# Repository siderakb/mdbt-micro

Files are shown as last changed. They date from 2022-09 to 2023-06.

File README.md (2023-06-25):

# MDBTMicro

v1.3

*MDBTMicro-50Q* is an alternative board to [nRFMicro](https://github.com/joric/nrfmicro)/Pro Micro.

It has USB Type-C and LiPo charger, uses Raytac [MDBT50Q-*x*1MV2](https://www.raytac.com/product/ins.php?index_id=24) nRF52840 module (or [MDBT50Q-*x*512K](https://www.raytac.com/product/ins.php?index_id=95) nRF52833 module) instead of E73-2G4M08S1.

Go to [Releases](https://github.com/siderakb/mdbt-micro/releases) for schematic and Gerber files.

> A part of [ErgoSNM keyboard](https://github.com/siderakb/ergo-snm-keyboard) project.  
> EDA: KiCad  

## PCB
| Front | Back | Layers |
| --- | --- | --- |
|  |  |  |

## BOM
| Designator | Value | Footprint |
| --- | --- | --- |
| C1,C2 | 1uF | 0603 (1608 Metric) |
| C3,C4 | 12pF | 0603 (1608 Metric) |
| R1 | 100k | 0603 (1608 Metric) |
| R2,R4 | 1k | 0603 (1608 Metric) |
| R3 | *Rprog* | 0603 (1608 Metric) |
| R5 | 1k | **0402 (1005 Metric)** |
| R6 | 820k | 0603 (1608 Metric) |
| R7,R8 | 2M | 0603 (1608 Metric) |
| R9,R10 | 5.1k | 0603 (1608 Metric) |
| D1 | 1N5819 | SOD-323F |
| J2 | USB_C_Receptacle_USB2.0 | 918-418K2024S40000 |
| LD1 | Red | 0603 (1608 Metric) |
| LD2 | Blue | 0603 (1608 Metric) |
| LD3 | Green | **0402 (1005 Metric)** |
| Q1,Q2 | AO3407 | Package_TO_SOT_SMD:SOT-23 |
| U1 | XC6220B331MR-G | SOT-23-5 |
| U2 | MDBT50Q-x1MV2 | MDBT50Q |
| U3 | TP4057 | SOT-23-6 |
| X1 | 32.768kHz | 2Pin 3.2x1.5mm |

- Please note that the footprint of R5 and LD3 is 0402.
- R2, R3, U3 and LD1 are not necessary if LiPo charger is not required. 
- R6 and R7 are not necessary if LiPo battery monitor is not required.
- Adjust the LiPo charging current with the value of R3.
  - 20 kΩ: 50 mA
  - 10 kΩ: 100 mA
  - 5 kΩ: 200 mA
  - 4 kΩ: 250 mA
  - 3 kΩ: 300 mA
  - 2 kΩ: 400 mA
  - 1.6 kΩ: 500 mA 
- XC6220B331MR-G can be replaced by AP2112K-3.3.
- MDBT50Q module includes MDBT50Q-1MV2/P1MV2/U1MV2 (nRF52840-based), or MDBT50Q-512K/P512K/U512K (nRF52833-based).

There is not designator silkscreen on PCB, please use your browser to open the `ibom.html` file (placed in [release page][release]) to refer to the placement of the parts, it is generated by [Interactive HTML BOM](https://github.com/openscopeproject/InteractiveHtmlBom) plugin.

## Pinout
| MDBTMicro-50Q `1.4` | nRFMicro `1.4` | Pro Micro | <--> | Pro Micro | nRFMicro `1.4` | MDBTMicro-50Q `1.4` |
| :---: | :---: | :---: | :---: | :---: | :---: | :---: |
| GND | GND | -- | | -- | VBAT | VBAT |
| P0.06 | P0.06 | D1/Tx | | RAW | VBAT | VBUS (USB 5V) |
| P0.08 | P0.08 | D0/Rx | | GND | GND | GND |
| GND | GND | GND | | RST |  P0.18/RESET | P0.18/RESET |
| GND | GND | GND | | VCC | VDD & VDDH | VDD & VDDH |
| P0.15 | P0.15 | D2 | | A3 | P0.30 | P0.30 |
| P0.17 | P0.17 | D3 | | A2 | P0.31 | P0.31 |
| P0.20 | P0.20 | D4 | | A1 | P0.29 | P0.29 |
| P0.13 | P0.13 | D5 | | A0 | P0.02 | P0.02 |
| P0.24 | P0.24 | D6 | | D15 | P1.13 | P1.13 (*P1.05*) |
| P0.09 | P0.09 | D7 | | D14 | P0.03 | P0.03 |
| P0.10 | P0.10 | D8 | | D16 | P0.28 | P0.28 |
| P1.06 | P1.06 | D9 | | D10 | P1.11 | P1.11 (*P1.04*) |
| | | | | | | |
| P1.10 (*P0.25*) | P1.10 | -- | LED Pin | | | |
| P0.04 | P0.04 | -- | Battery Pin | | | |
| P1.09 | P1.09 | -- |  Power Pin  | | | |
| P1.12 (*P0.23*) | -- | -- | TP1 | | | |
| P1.14 (*P1.03*) | -- | -- | TP2 | | | |
| P1.15 (*P0.19*) | -- | -- | TP3 | | | |
| P0.05 | -- | -- | TP4 | | | |
| P0.07 | -- | -- | TP5 | | | |
| P0.11 | -- | -- | TP6 | | | |
| P0.12 | -- | -- | TP7 | | | |

> Italics in brackets for MDBT50Q-*x*512K (nRF52833) pins, otherwise MDBT50Q-*x*1MV2 (nRF52840).  
> Almost the same as [nRFMicro 1.4](https://github.com/joric/nrfmicro/releases/tag/1.4)

## Jumper Config
- JP1
  - nRF52840: Open
  - nRF52833: Close

## Board Characteristics
- Copper layer count: 2
- Board overall dimensions: 33.02 mm x 17.78 mm (1.3 x 0.7 inch)
- Min track/spacing: 0.127 mm / 0.127 mm
- Min hole diameter: 0.3 mm

## Disclaimer
These files without warranty of any kind, use at your own risk, it is recommended to check yourself before manufacture.

For the full statement, please see [LICENSE](./LICENSE).

[release]: https://github.com/ziteh/mdbt-micro/releases

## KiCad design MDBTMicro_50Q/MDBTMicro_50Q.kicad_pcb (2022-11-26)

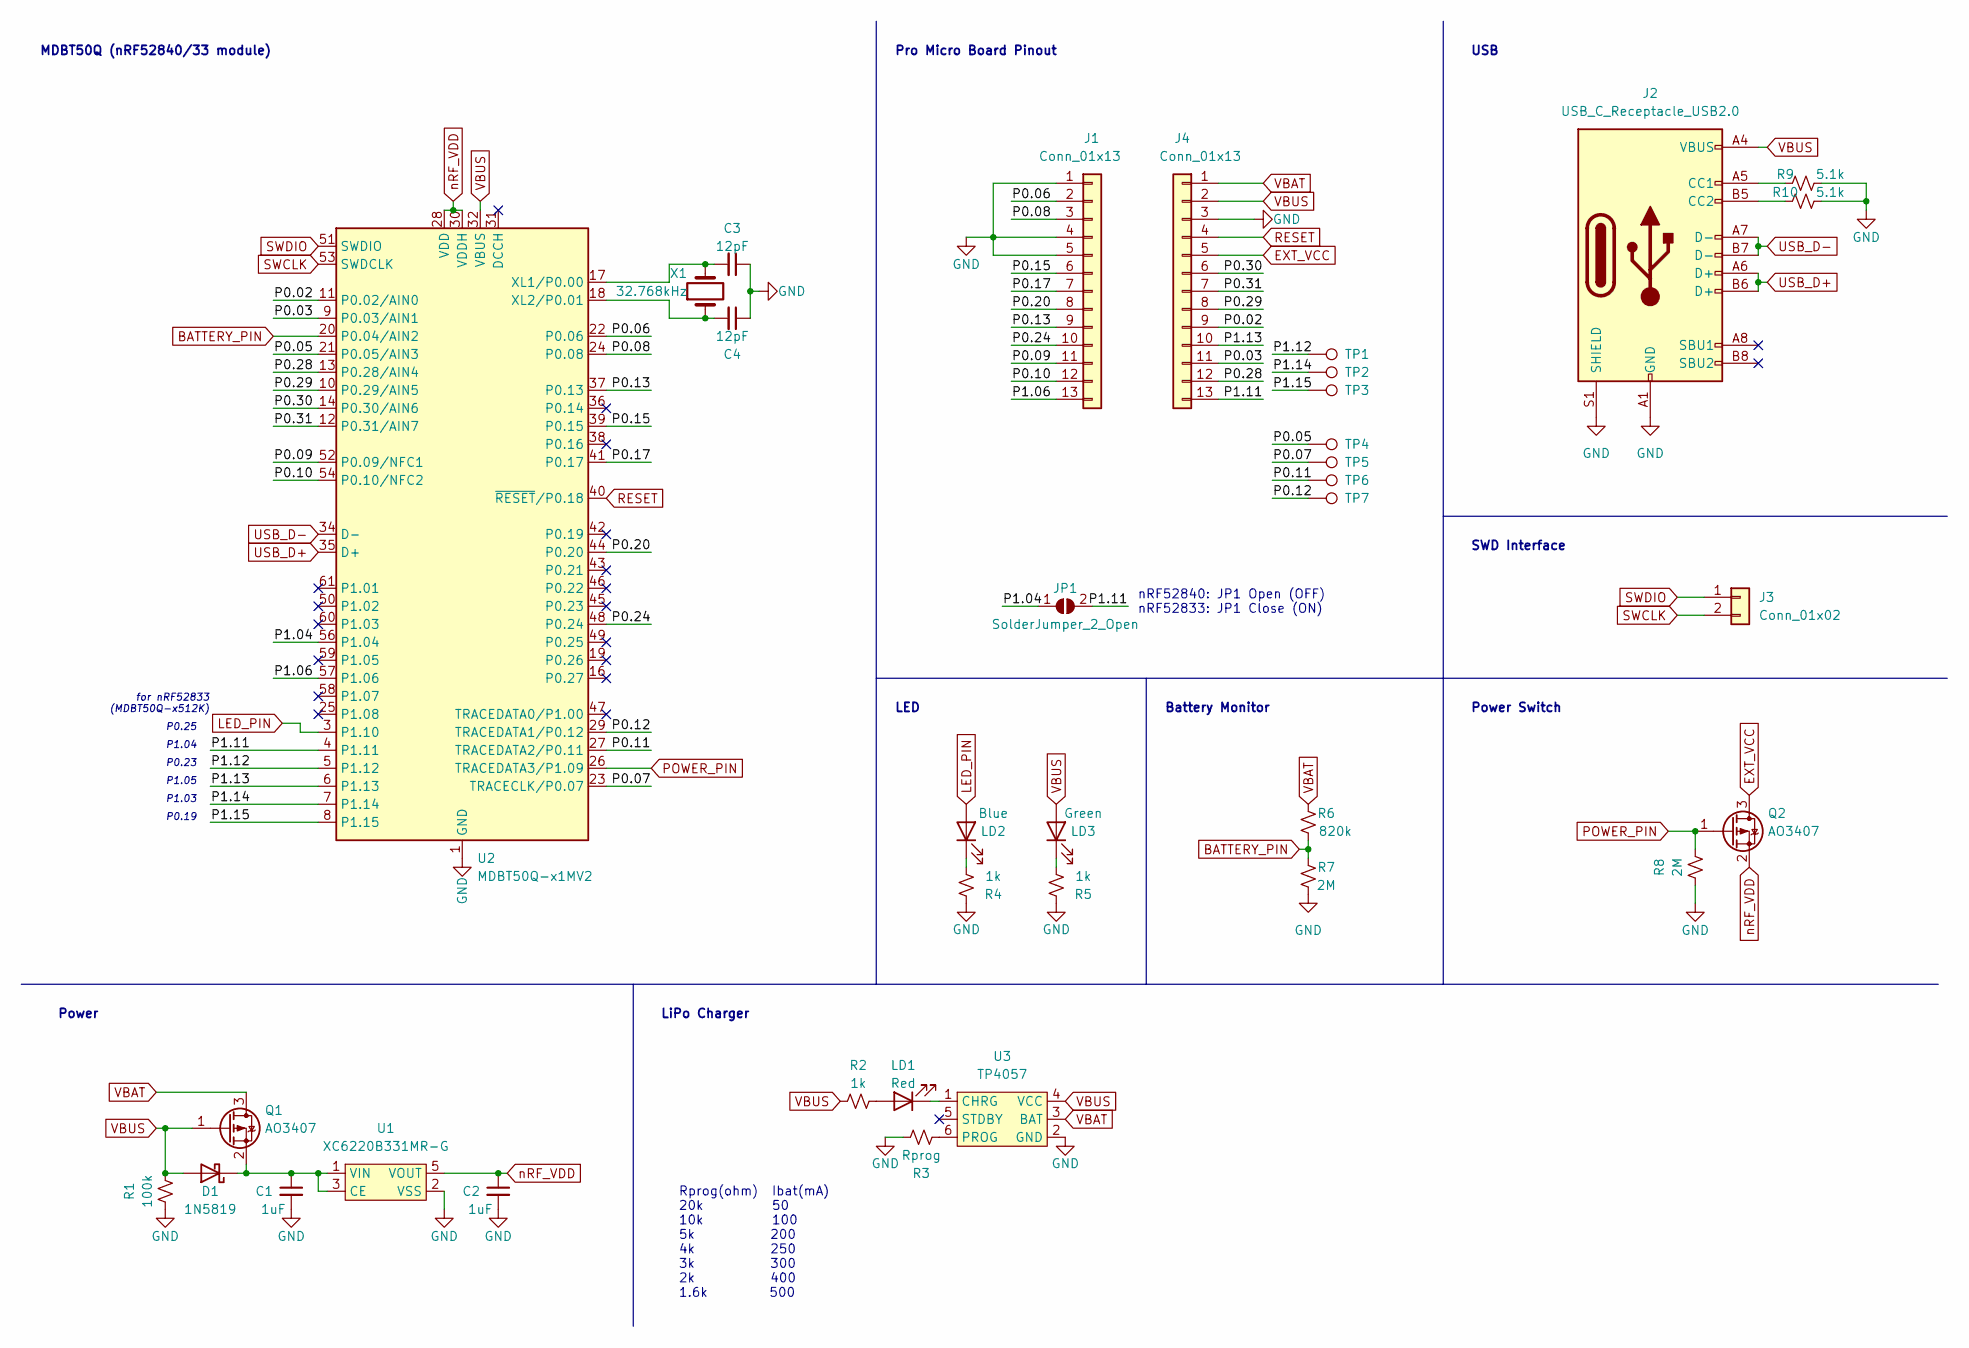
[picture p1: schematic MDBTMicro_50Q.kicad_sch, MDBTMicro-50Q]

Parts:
C1, C2: 1uF; C_0603_1608Metric
C3, C4: 12pF; C_0603_1608Metric
D1: 1N5819; D_SOD-323F
J1, J4: Conn_01x13; PinHeader_1x13_P2.54mm_Vertical
J2: USB_C_Receptacle_USB2.0; USB Type-C Mid-Mount Receptacle 16P
J3: Conn_01x02; PinHeader_1x02_P2.54mm_Vertical
JP1: SolderJumper_2_Open; SolderJumper-2_P1.3mm_Open_TrianglePad1.0x1.5mm
LD1: Red; LED_0603_1608Metric
LD2: Blue; LED_0603_1608Metric
LD3: Green; LED_0402_1005Metric
Q1, Q2: AO3407; SOT-23
R1: 100k; R_0603_1608Metric
R2, R4: 1k; R_0603_1608Metric
R3: Rprog; R_0603_1608Metric
R5: 1k; R_0402_1005Metric
R6: 820k; R_0603_1608Metric
R7, R8: 2M; R_0603_1608Metric
R9, R10: 5.1k; R_0603_1608Metric
TP1, TP2, TP3, TP4, TP5, TP6, TP7: TestPoint; TestPoint_Pad_D1.0mm
U1: XC6220B331MR-G; SOT-23-5
U2: MDBT50Q-x1MV2; Raytac_MDBT50Q
U3: TP4057; SOT-23-6
X1: 32.768kHz; Crystal_SMD_MicroCrystal_CC7V-T1A-2Pin_3.2x1.5mm

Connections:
/P0.02: J4.9, U2.11 (P0.02/AIN0)
/P0.03: J4.11, U2.9 (P0.03/AIN1)
/P0.05: TP4.1, U2.21 (P0.05/AIN3)
/P0.06: J1.2, U2.22 (P0.06)
/P0.07: TP5.1, U2.23 (TRACECLK/P0.07)
/P0.08: J1.3, U2.24 (P0.08)
/P0.09: J1.11, U2.52 (P0.09/NFC1)
/P0.10: J1.12, U2.54 (P0.10/NFC2)
/P0.11: TP6.1, U2.27 (TRACEDATA2/P0.11)
/P0.12: TP7.1, U2.29 (TRACEDATA1/P0.12)
/P0.13: J1.9, U2.37 (P0.13)
/P0.15: J1.6, U2.39 (P0.15)
/P0.17: J1.7, U2.41 (P0.17)
/P0.20: J1.8, U2.44 (P0.20)
/P0.24: J1.10, U2.48 (P0.24)
/P0.28: J4.12, U2.13 (P0.28/AIN4)
/P0.29: J4.8, U2.10 (P0.29/AIN5)
/P0.30: J4.6, U2.14 (P0.30/AIN6)
/P0.31: J4.7, U2.12 (P0.31/AIN7)
/P1.04: JP1.1 (A), U2.56 (P1.04)
/P1.06: J1.13, U2.57 (P1.06)
/P1.11: J4.13, JP1.2 (B), U2.4 (P1.11)
/P1.12: TP1.1, U2.5 (P1.12)
/P1.13: J4.10, U2.6 (P1.13)
/P1.14: TP2.1, U2.7 (P1.14)
/P1.15: TP3.1, U2.8 (P1.15)
BATTERY_PIN: R6.1, R7.2, U2.20 (P0.04/AIN2)
EXT_VCC: J4.5, Q2.3 (D)
GND: C1.2, C2.2, C3.1, C4.1, J1.1, J1.4, J1.5, J2.A1 (GND), J2.A12 (GND), J2.B1 (GND), J2.B12 (GND), J2.S1 (SHIELD), J4.3, R1.2, R3.1, R4.1, R5.1, R7.1, R8.2, R9.2, R10.2, U1.2 (VSS), U2.1 (GND), U2.2 (GND), U2.15 (GND), U2.33 (GND), U2.55 (GND), U3.2 (GND)
LED_PIN: LD2.2 (A), U2.3 (P1.10)
unnamed: C1.1, D1.1 (K), Q1.2 (S), U1.1 (VIN), U1.3 (CE)
unnamed: C3.2, U2.17 (XL1/P0.00), X1.2
unnamed: C4.2, U2.18 (XL2/P0.01), X1.1
unnamed: J2.A5 (CC1), R9.1
unnamed: J2.B5 (CC2), R10.1
unnamed: LD1.1 (K), U3.1 (CHRG)
unnamed: LD1.2 (A), R2.1
unnamed: LD2.1 (K), R4.2
unnamed: LD3.1 (K), R5.2
unnamed: R3.2, U3.6 (PROG)
POWER_PIN: Q2.1 (G), R8.1, U2.26 (TRACEDATA3/P1.09)
RESET: J4.4, U2.40 (~RESET/P0.18)
SWCLK: J3.2, U2.53 (SWDCLK)
SWDIO: J3.1, U2.51 (SWDIO)
USB_D+: J2.A6 (D+), J2.B6 (D+), U2.35 (D+)
USB_D-: J2.A7 (D-), J2.B7 (D-), U2.34 (D-)
VBAT: J4.1, Q1.3 (D), R6.2, U3.3 (BAT)
VBUS: D1.2 (A), J2.A4 (VBUS), J2.A9 (VBUS), J2.B4 (VBUS), J2.B9 (VBUS), J4.2, LD3.2 (A), Q1.1 (G), R1.1, R2.2, U2.32 (VBUS), U3.4 (VCC)
nRF_VDD: C2.1, Q2.2 (S), U1.5 (VOUT), U2.28 (VDD), U2.30 (VDDH)

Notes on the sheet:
Pro Micro Board Pinout
P0.19
LiPo Charger
P0.23
Power Switch
SWD Interface
P1.05
Battery Monitor
Power
Rprog(ohm) Ibat(mA) 20k 50 10k 100 5k 200 4k 250 3k 300 2k 400 1.6k 500
P1.03
P1.04
for nRF52833 (MDBT50Q-x512K)
MDBT50Q (nRF52840/33 module)
USB
P0.25
LED
nRF52840: JP1 Open (OFF) nRF52833: JP1 Close (ON)

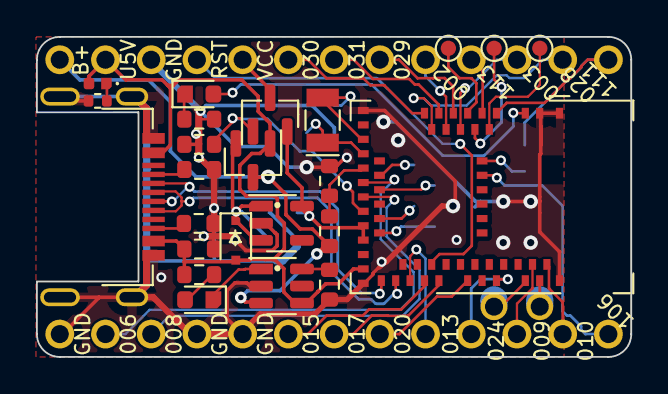
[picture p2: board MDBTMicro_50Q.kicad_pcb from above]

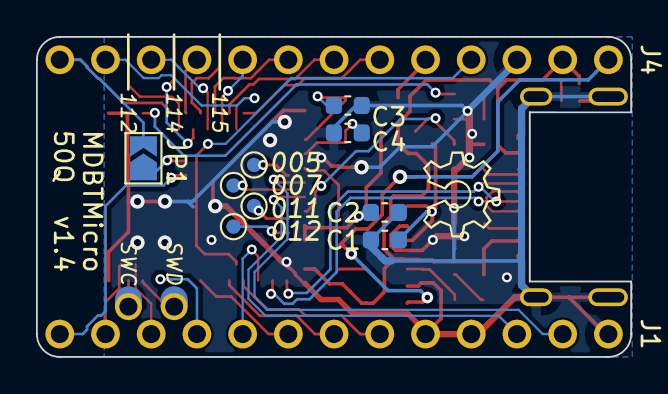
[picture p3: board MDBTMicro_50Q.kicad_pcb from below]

Board: 2 copper layers, 33.0 x 17.8 mm, 36 parts (11 on the bottom side), 49 nets.

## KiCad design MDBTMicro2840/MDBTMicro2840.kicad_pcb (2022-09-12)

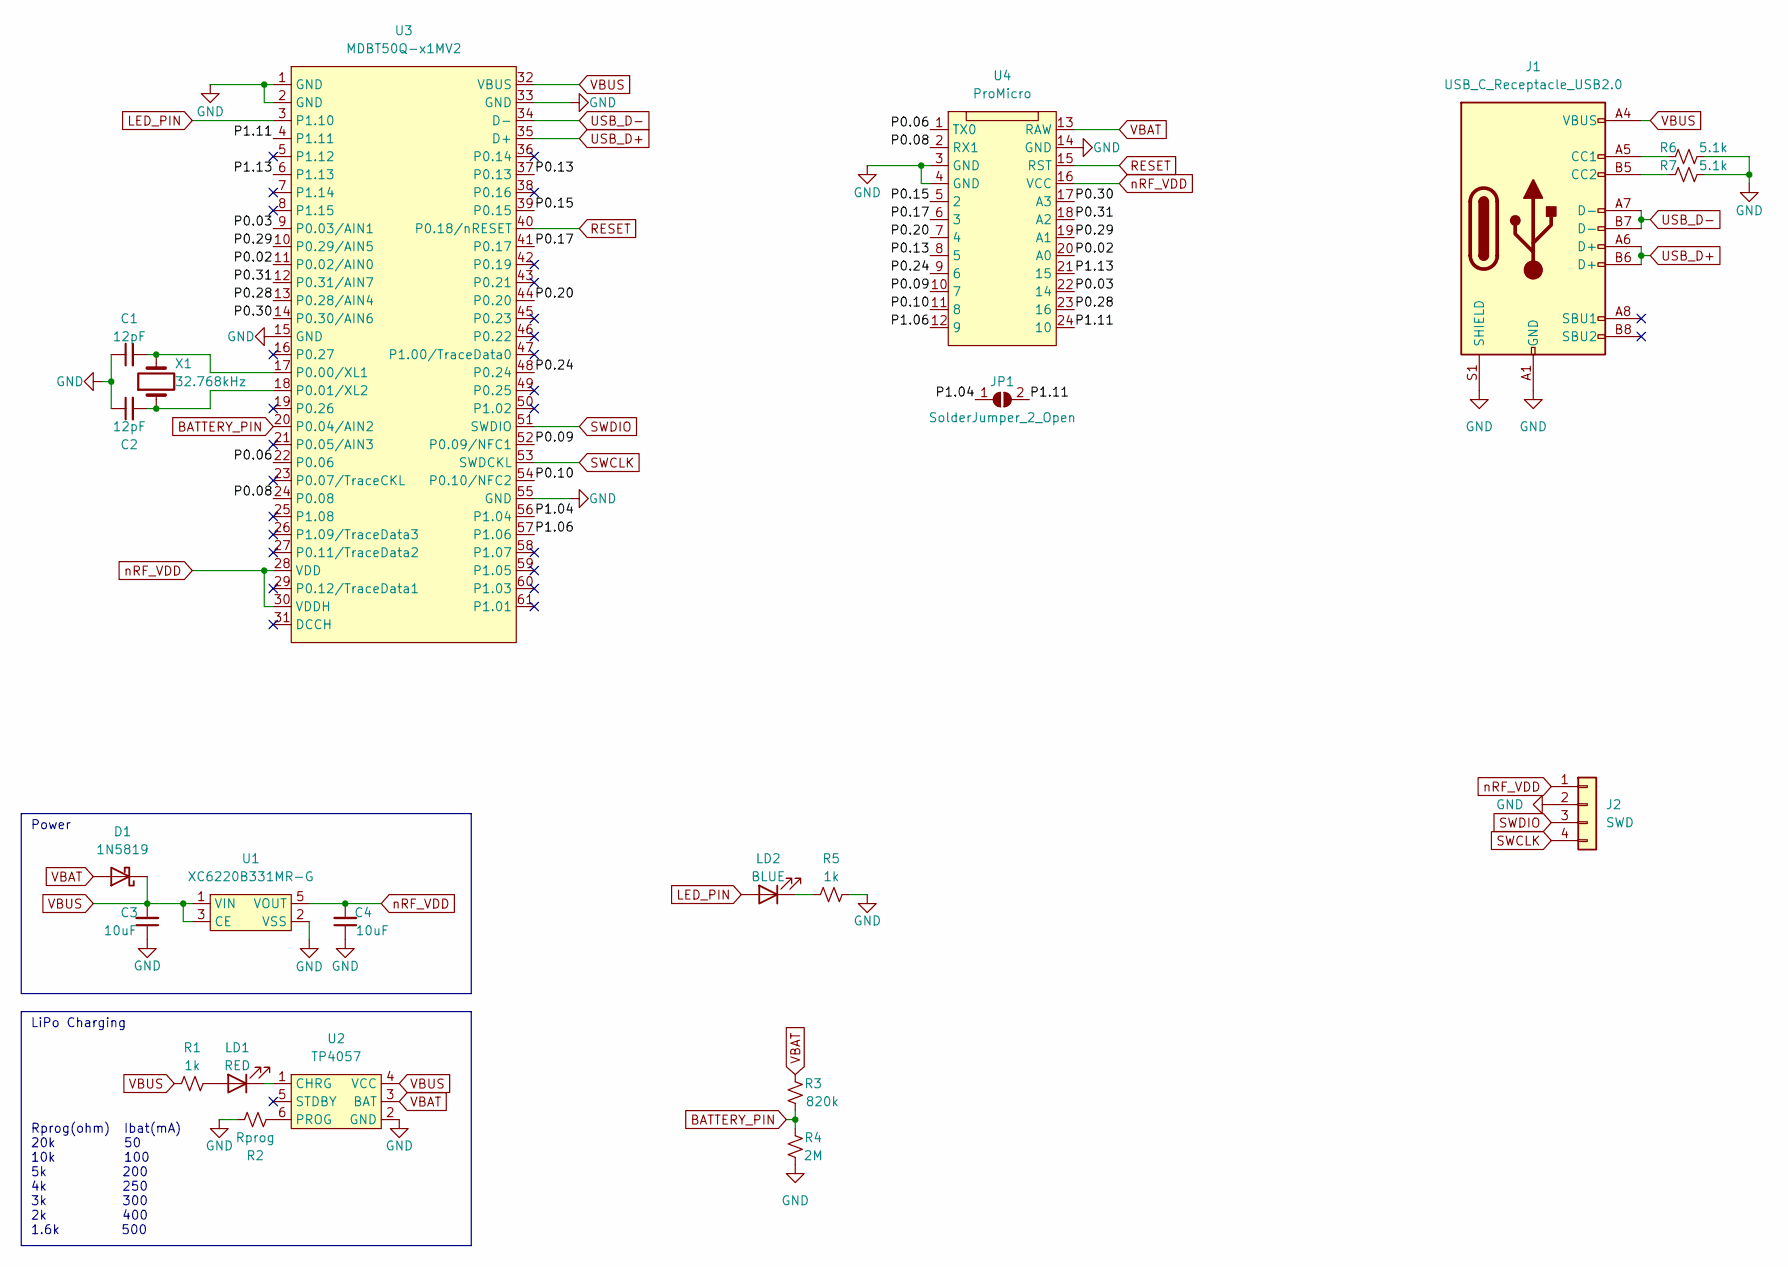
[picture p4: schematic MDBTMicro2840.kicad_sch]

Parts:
C1, C2: 12pF; C_0201_0603Metric
C3, C4: 10uF; C_0201_0603Metric
D1: 1N5819; D_SOD-123
J1: USB_C_Receptacle_USB2.0; USB Type-C Mid-Mount Receptacle 16P
J2: SWD; PinHeader_1x04_P1.00mm_Vertical
JP1: SolderJumper_2_Open; SolderJumper-2_P1.3mm_Open_TrianglePad1.0x1.5mm
LD1: RED; LED_0201_0603Metric
LD2: BLUE; LED_0201_0603Metric
R1, R5: 1k; R_0201_0603Metric
R2: Rprog; R_0201_0603Metric
R3: 820k; R_0201_0603Metric
R4: 2M; R_0201_0603Metric
R6, R7: 5.1k; R_0201_0603Metric
U1: XC6220B331MR-G; SOT-25-5
U2: TP4057; SOT-23-6
U3: MDBT50Q-x1MV2; Raytac_MDBT50Q
U4: ProMicro
X1: 32.768kHz; Crystal_SMD_3215-2Pin_3.2x1.5mm

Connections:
/P0.02: U3.11 (P0.02/AIN0), U4.20 (A0)
/P0.03: U3.9 (P0.03/AIN1), U4.22 (14)
/P0.06: U3.22 (P0.06), U4.1 (TX0)
/P0.08: U3.24 (P0.08), U4.2 (RX1)
/P0.09: U3.52 (P0.09/NFC1), U4.10 (7)
/P0.10: U3.54 (P0.10/NFC2), U4.11 (8)
/P0.13: U3.37 (P0.13), U4.8 (5)
/P0.15: U3.39 (P0.15), U4.5 (2)
/P0.17: U3.41 (P0.17), U4.6 (3)
/P0.20: U3.44 (P0.20), U4.7 (4)
/P0.24: U3.48 (P0.24), U4.9 (6)
/P0.28: U3.13 (P0.28/AIN4), U4.23 (16)
/P0.29: U3.10 (P0.29/AIN5), U4.19 (A1)
/P0.30: U3.14 (P0.30/AIN6), U4.17 (A3)
/P0.31: U3.12 (P0.31/AIN7), U4.18 (A2)
/P1.04: JP1.1 (A), U3.56 (P1.04)
/P1.06: U3.57 (P1.06), U4.12 (9)
/P1.11: JP1.2 (B), U3.4 (P1.11), U4.24 (10)
/P1.13: U3.6 (P1.13), U4.21 (15)
BATTERY_PIN: R3.1, R4.2, U3.20 (P0.04/AIN2)
GND: C1.1, C2.1, C3.1, C4.1, J1.A1 (GND), J1.A12 (GND), J1.B1 (GND), J1.B12 (GND), J1.S1 (SHIELD), J2.2, R2.1, R4.1, R5.1, R6.2, R7.2, U1.2 (VSS), U2.2 (GND), U3.1 (GND), U3.2 (GND), U3.15 (GND), U3.33 (GND), U3.55 (GND), U4.3 (GND), U4.4 (GND), U4.14 (GND)
LED_PIN: LD2.2 (A), U3.3 (P1.10)
unnamed: C1.2, U3.17 (P0.00/XL1), X1.2
unnamed: C2.2, U3.18 (P0.01/XL2), X1.1
unnamed: J1.A5 (CC1), R6.1
unnamed: J1.B5 (CC2), R7.1
unnamed: LD1.1 (K), U2.1 (CHRG)
unnamed: LD1.2 (A), R1.1
unnamed: LD2.1 (K), R5.2
unnamed: R2.2, U2.6 (PROG)
RESET: U3.40 (P0.18/nRESET), U4.15 (RST)
SWCLK: J2.4, U3.53 (SWDCKL)
SWDIO: J2.3, U3.51 (SWDIO)
USB_D+: J1.A6 (D+), J1.B6 (D+), U3.35 (D+)
USB_D-: J1.A7 (D-), J1.B7 (D-), U3.34 (D-)
VBAT: D1.2 (A), R3.2, U2.3 (BAT), U4.13 (RAW)
VBUS: C3.2, D1.1 (K), J1.A4 (VBUS), J1.A9 (VBUS), J1.B4 (VBUS), J1.B9 (VBUS), R1.2, U1.1 (VIN), U1.3 (CE), U2.4 (VCC), U3.32 (VBUS)
nRF_VDD: C4.2, J2.1, U1.5 (VOUT), U3.28 (VDD), U3.30 (VDDH), U4.16 (VCC)

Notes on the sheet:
LiPo Charging
Power
Rprog(ohm) Ibat(mA) 20k 50 10k 100 5k 200 4k 250 3k 300 2k 400 1.6k 500

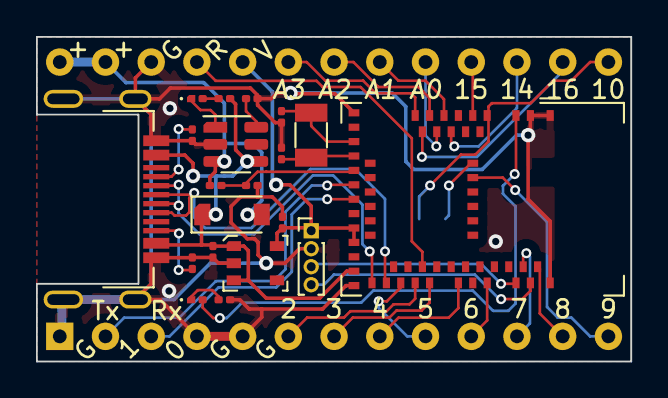
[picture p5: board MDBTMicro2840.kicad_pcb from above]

Board: 2 copper layers, 33.0 x 18.0 mm, 22 parts (1 on the bottom side), 38 nets.

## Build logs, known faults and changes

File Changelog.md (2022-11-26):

# Changelog

## [1.4.0] 2022-11-26
### Removed
- Remove USB D+/- test pads.

### Changed
- Change SWD connecter footprint, makes it easier to solder.

## [1.3.0] 2022-10-18
### Added
- USB D+/- test pads added.

### Changed
- Replace all capacitors, resistors and LEDs footprint back to 0603 again, except R5 and LD3.

## [1.2.0] 2022-10-16
### Fixed
- Fixed the ProMicro board 2.54mm pin headers hole size from 0.7mm to 1mm.

### Added
- LD3 VBUS power indicator.

### Changed
- Move C1 and C2 away from the back of USB D+/- differential pair tracks.
- Reduce the size of board to 33.02x17.78mm (1.3x0.7 inch, same as ProMicro).

## [1.1.0] 2022-10-15
### Added
- Q1 P-MOSFET for LiPo battery load sharing.
- Q2 P-MOSFET for output Vcc switch.

### Changed
- Replace all capacitors, resistors and LEDs footprint from 0603 to 0402.
- Replace X1 crystal footprint from 1610 to 3215.
- Replace SWD connector from 1.27mm pin header to test pad (TP8 ~ TP10).
- Update the USB Type-C footprint.

## [1.0.0] 2022-09-13
First release.

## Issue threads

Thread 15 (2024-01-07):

支持E73-2G4M08S1？

XSJFYZS, 2024-01-07:
你好开发者
首先感谢你分享的开源项目
我正在制作1个无线轨迹球项目，但MDBT50Q在国内大陆很难购买，而E73-2G4M08S1C只需要15元人民币而已
我还想添加一个编码器用于网页滚动\音量控制
请问这个模块是否可以支持？谢谢

ziteh, 2024-01-07:
Hi
MDBT Micro 僅支援 MDBT50Q，如果你想要使用 E73 的話，推薦 [joric/nrfmicro](https://github.com/joric/nrfmicro)
它的 wiki 内有很詳細的介紹

XSJFYZS, 2024-01-07:
> 你好 MDBT Micro 仅支持 MDBT50Q，如果你想使用 E73 的话，推荐[joric/nrfmicro](https://github.com/joric/nrfmicro) 它的 wiki 内有很详细的介绍
>
> 也可以看看 SuperMini NRF52840

谢谢回复，我先学习一下

ziteh, 2024-05-27:
Close inactive issue, and please feel free to reopen it if needed : )

Closed 2024-05-27.

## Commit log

2022-09-10 Add KiCAD project 'MDBTMicro2840'
    [MDBTMicro2840.kicad_pcb, MDBTMicro2840.kicad_sch]
2022-09-10 Update sch info
    [MDBTMicro2840.kicad_sch]
2022-09-10 Remove unused files
    [MDBTMicro2840.kicad_sch]
2022-09-10 Update sch
    [MDBTMicro2840.kicad_pcb, MDBTMicro2840.kicad_sch]
2022-09-11 Update USB footprint
    [MDBTMicro2840.kicad_pcb, MDBTMicro2840.kicad_sch]
2022-09-11 Update to pass the DRC
    [MDBTMicro2840.kicad_pcb]
2022-09-11 Update gerber config for JLCPCB
    [MDBTMicro2840.kicad_pcb]
2022-09-12 Update 1N5819 footprint to SOD123
    [MDBTMicro2840.kicad_pcb, MDBTMicro2840.kicad_sch]
2022-09-12 Update silkscreen
    [MDBTMicro2840.kicad_pcb]
2022-09-12 Update footprint
    [MDBTMicro2840.kicad_pcb, MDBTMicro2840.kicad_sch]
2022-09-12 Files rename
    [MDBTMicro_50Q.kicad_pcb, MDBTMicro_50Q.kicad_sch]
2022-09-12 Rename folder
    [MDBTMicro_50Q.kicad_pcb, MDBTMicro_50Q.kicad_sch]
2022-09-13 Update sch and pcb
    [MDBTMicro_50Q.kicad_pcb, MDBTMicro_50Q.kicad_sch]
2022-09-13 Place origin
    [MDBTMicro_50Q.kicad_pcb]
2022-09-15 Update page setting
    [MDBTMicro_50Q.kicad_sch]
2022-10-15 Add origin
    [MDBTMicro_50Q.kicad_pcb]
2022-10-16 Remove unused footprint
2022-10-20 Update silk screen
    [MDBTMicro_50Q.kicad_pcb]

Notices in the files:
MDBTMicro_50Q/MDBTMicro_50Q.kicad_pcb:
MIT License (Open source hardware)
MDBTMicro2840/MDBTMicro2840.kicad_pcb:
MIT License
